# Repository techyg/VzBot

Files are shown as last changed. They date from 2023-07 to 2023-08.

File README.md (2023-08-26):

# Mellow VzBot 330 Kit Information

This is a repository for VZbot mods and info as I went through my build, in July of 2023. I am optimistic the kit will continue to improve. 

Check out my videos here to learn more about this build, including printed part options, first impressions, and a compelte build series. 

https://www.youtube.com/watch?v=h90rvTm2mc8&list=PLpQnpsv1trbRPkbdpc53gmuK3JUCKimgY

Based in the US? Buy your VzBot from Provok3d, who sponsored my build.

https://provok3d.com/product/mellow-vz330-awd/?v=0a10a0b3e53b

# Detailed Info

This content is intended to augment my videos and has more detail that may be helpful for you. This document also includes links to additional components and recommendations for tools that you may need for your build. 

https://github.com/techyg/VzBot/blob/main/Mellow%20VZ%20Bot%20330%20Initial%20impressions.pdf

*** The kit also has several missing fasteners and room for improvement. ** This is not a comprehensive list, but will give you an idea of what additional components you may need to purchase for your kit. I list the missing fastners here as well as some other suggestions for improving the kit.

https://github.com/techyg/VzBot/blob/main/Mellow%20Fly%20Kit%20Suggestions%20VzBot%20330%20Kit.pdf

# Printed Parts

2020 Endscap - Mellow Fly 330 Remix.stl: The stock parts for the 2020 covers are too long and hit the bolt. I created the remix that will work with the Mellow Fly extrusion. You will need to print 8 of these.

VzHextrudort_Motor_Spacer_v1.stl: This helps insulate the motor the heat. I ran into an issue where my motor was causing lower temp filament (PETG) to deform/clog in the extruder due to excessive heat. This is only .5mm thick- print this at a low layer height (.1mm is what I used). I remixed this, original part is from Thingiverse. https://www.thingiverse.com/thing:5777803

If you plan to print PLA or PETG, I definitely recommend using the motor spacer / heat shield. In my testing, I noticed a significant difference in the temp of the extruder vs. the motor, compared to NOT using it. This is because the motor will transfer heat to the extruder much more easily without the motor shield. While it was a little challenging to get exact temps of the motor, using an IR gun I never exceed 60C temps on the extruder and I believe the motor was around 80C. Note that I also did not have the top hat on when printing (but doors were closed), and I also lowered my motor current to .6. 

# Config & Slicer Files

This folder includes all of the printer.cfg and related files that I use. Files are all based on the "stock" VzBot configuration.

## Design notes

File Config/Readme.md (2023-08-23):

Here you find all the files that I am using for my "mostly stock" Mellow VZBot 330 printer, which includes the following:

* Super 8 Pro board
* Goliath Hot End with stock heater cartridge, 24v fan, Generic 3950 Thermistor because my Mellow Fly one broke during install.
* 5160 external stepper motors for X, X1, Y, Y1 run at 48v; single 2209 drivers for E and Z at 24v.
* 750 Watt AC Bed
* Limit switches for X, Y, Z
* CPAP Cooling fan wired to Super 8
* Exhaust fan, RSCS Fans. I am using an external MOSFET to power the RSCS fan due to the higher amp draw. 
* Include file for Provok3d nozzle board. (Optional)

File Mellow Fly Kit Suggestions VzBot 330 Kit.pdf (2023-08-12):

Mellow Fly Kit Sugges0ons VzBot 330 Kit (July 2023 Build)

Installing Corner Brackets: M4 screws are intended here, but heads are too small.
- Include M4 Washers
- Or, provide 12 addi0onal m5x10 BHCS screws with Tnuts

Z Assembly- M3x45’s were needed but not included.
- Provide a quan0ty of 4 M3x45’s SCHS

Heat Inserts will be needed throughout the build (including toolhead, and other loca0ons)
- Include a bag of small M3 heat inserts (3x4mm)

Toolhead requires 2 M3x30 screws that go inside spacers that were not included.
- Include 2 M3x30 screws

AC Inlet is not of sufficient quality.
- Consider providing a "US" version of the AC inlet, with proper IEC wiring colors and a 10A fuse op0on, rather than the included 5A which is probably fine for Europe but not US (since we have half the voltage of EU, so need double the current).

Back Panel
- I ran out of M4x10 screws
- Include an addi0onal 20 M4x10 BHCS

Feet (Assuming Stock feet)
- Include 4 M4x25 SCHS length screws for installing rubber feet
- Include 8 M4x20 SCHS length screws for remaining feet screws

Super 8 Board Moun0ng
- Include M3x8 SHCS (quan0ty at least 10)

Electronics Connectors
- Only spade terminals for Super 8 Pro board are included in kit.
- Include proper sized Spade terminals for 24v and 48v power supply. Recommend at least a 20 pack. (3 for AC input x 2, 6 spaces for +/- x2 on 24v and 48v).
- Include a pack of assorted ferrules for 5160 motor connectors and hot end heater

Wiring
- Include heat shrink that can accommodate 20-24 awg wiring, used for endstops
- Include zip 0es
- Include 6mm and 12mm braided sleeve for keeping back panel wiring 0dy, and for toolhead wire loom / umbilical

CPAP
- Include M2x6 self-tapping screws for CPAP board mount

Exhaust Fan
- Kit was missing 4x M4x50’s. Include those.

RSCS & Side Panels
- Kit was missing m5x12 self-tapping screws. Instead it included M4. I used heat inserts for the fans with M3 screws and washers as a subs0tute. Recommend including the M5x12 self-tapping screws.
- Side panel install required a significant amount of M4x10 screws, and at this point I didn’t have any led. Recommend including at least another 20-30 M4x10’s. At this point I think we’re up to 40 missing M4x10’s.

Front Panels
- 4 Heat inserts needed for latches. Include a small bag of heat inserts.

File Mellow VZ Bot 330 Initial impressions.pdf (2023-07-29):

Mellow VZ Bot 330
Sponsored by Provok3d.com
July 2023

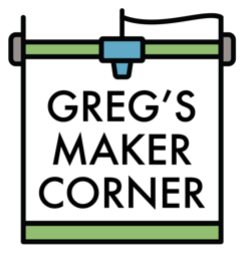
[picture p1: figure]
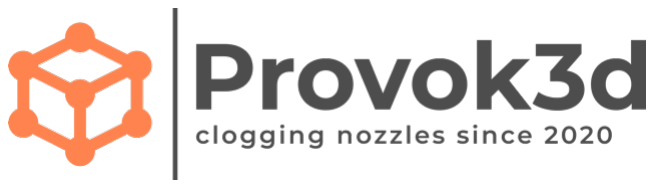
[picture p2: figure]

This document is a writeup of my ini4al impressions immediately following my VzBot 330 Mellow build, which is intended to augment my Ini4al Impressions video posted on Youtube.

Find my Youtube Channel here: h?p://www.gregsmakercorner.com/

If you are considering buying a VzBot 3d printer and are based in the United States, please consider buying from Provok3d who is one of the few authorized dealers in the US. This company sponsored my build and I am VERY appreciaJve!

hJps://provok3d.com/vzbot-330/?v=0a10a0b3e53b

Overall Summary
- Building a VzBot is an ambitious but rewarding build. This machine is intended for DIY enthusiasts and tweakers who want to push 3d printing to the limits. While other DIY designs may offer similar benefits, you might spend a bit more time tweaking, upgrading and going down rabbit holes on to get there.
- With the VzBot, you can expect high speeds (10-20K acceleration, 500 mm/sec as a starting point) with a large build volume (330mm) immediately after completing a well-built, squared and fully tightened printer. With a finely tuned machine, you can expect to achieve 50K-100K accelerations and print beyond 1 meter per second. Wow!
- At the present time, this level of speed and performance is not available "off the shelf" though printers like the Bambu P1P are definitely gaining ground.
- For my very first print, I used a 10K acceleration and 300 mm/sec print speed. The printer had no issue keeping up though it jolts around a bit because the table the printer sat on was not very stable. While I have only done initial testing, I believe this printer easily lives up to the promises of high speed.
- The Mellow Fly VzBot does include the necessary components (CPAP fan, RSCS fans, Goliath hot end) to achieve amazing speeds. However, keep in mind that in order to achieve these speeds you will need a very sturdy and stable surface, and may need to bolt the printer down. You will also need to take many steps to tune and calibrate the printer.
- The Mellow Fly VzBot does not rely on printed parts for any crucial parts of the drive train and gantry, but instead uses CNC metal parts which provides an increased level of rigidity that is suited for high speed and high temp printing. It is possible to build a VzBot with printed parts and still get good results, however.

- With that in mind, you will still need 2 rolls (1kg each) of primary color and 1 roll (1kg) of accent color.
- The VzBot 330 Mellow Kit does not include everything you need to complete the printer build, but it does include most components. See the end of this document for additional part recommendations, tools, etc.
- The Vzbot 330 is an open-source design, with the exception of the CNC metal parts which must be obtained from 3rd party vendors.
- The Github for VzBot 330 design s here: https://github.com/VzBoT3D/VzBoT-Vz330
- According to the Github documentation, a VzBot 330 can be sourced starting at $800. The Mellow Kit is around $1600 but also includes CNC parts and many other high-end components like LDO Super Power motors and rails.

Want to see my build log? Join the VzBot discord and check it out here:

https://discord.com/channels/829828765512106054/1128354020566777938

My recommendations
- I recommend the VzBot Mellow kit for experienced builders who want to be on the cutting edge of 3d printing and squeeze every ounce of performance out of a printer.
- This printer is also ideal for those who want fast print time without having to buy multiple machines and enjoy tinkering and tweaking.
- If you are new to 3d printing I recommend building a Voron 0 first, which would be an excellent printer to “boot strap” many of the parts for this machine which need to be printed in ASA or ABS and will also test your skills/readiness. If you can successfully build a Voron 0 you should be able to complete this build without too many issues.
- This is a DIY printer and building/tweaking is a hobby in itself. If you are mainly interested in the outcome of printing (3d printed parts) and do not enjoy tweaking, fixing, etc. look elsewhere.

VZBot Build Process
- The VzBot documentation has been emerging from simple Github pages with pictures, to what I would consider an "MVP" (minimum viable product) philosophy. Think of the manual more as guidelines vs. step by step instructions.
- I went into this build with the idea that I would build it as stock as possible. There were a few places I was tempted to go outside of stock but for the most part I resisted the urge and stuck with the intended design. I felt this would be best to give a good review of the kit and help guide other builders.

Mellow Fly Kit
- The Mellow kit is a good start and has high quality components where it really matters, especially for the motors and of course CNC parts. You will definitely need to augment your kit with additional components to complete it. There are some obvious components that you will need- for example a Raspberry Pi or equivalent. I also needed several different sizes of fasteners that weren't included. I've listed the vast majority of components I used in the video description if you would like to get a feel. Expect to spend around $xx-$xxx depending on what you may already have on hand.

Build Time

- It took me less than 3 weeks to build this printer. I was working on it part-time, weekends and evenings, and also recording video along the way. An experienced builder who has previously built Core XY printers (such as Voron, RatRig, or Annex) could possibly complete the build in a long weekend "best case". Realistically, I would budget at least 1-2 weeks to build.

Mechanical Build
- The mechanical build was very straight forward up until back panel. The build complexity is very similar to build a Voron Trident, or a Prusa Mk3/4.
- Unfortunately, the panels needed additional prep work. Drilling was required to open up holes for power supply (which were too tight), and new holes were required for DIN Rail mounting.
- Drilling aluminum is not particularly difficult with the proper tools, but it may be a barrier for some.

Electronics, Wiring and Crimping:

- The electronics portion of the build is tedious and time consuming, and could be a significant challenge especially for those who do not have experience crimping, soldering, etc.
- WARNING. The Mellow Fly kit I received included an under spec’d AC power inlet, and it should be discarded. Some builders have reported the inlet melting when heating both the bed and hot end, which draws a significant amount of power. I purchased a replacement AC inlet on Amazon but it would be best to get one (a standard c14 ac inlet) from a reputable company like Mouser or Digikey ideally with a certification.
- You will be working with mains power, two power supplies (24v and 48v), and an SSR for the AC bed. While this isn't difficult to wire up, you really need to use care while wiring and also make sure you are earthing properly. Consult with an electrician if you are not sure.
- You will need to carefully consider layout of the wiring. The VzBot design team deliberately does not prescribe a wiring layout, because there are so many possible directions to take, as well as optional/potential upgrades. For example, some builders may opt for multiple SSR's for high temp chamber heating, as well as additional fans.
- My kit did not include very many connectors outside of JST and a few small spade terminals for the Super 8 Pro board. With that in mind you will need to source these depending on the direction you go. You will also need several different crimpers. I ended up crimping Spade Terminals for power supplies, Raspberry Pi, JST PH for fan connectors to the 5160's, Ferrules for the 5160's, and JST XH connectors for many other connections (fans, thermistors, etc.).

Where I ran into challenges

- On occasion the manual was not as clear as I was hoping, and I had to consult the CAD diagram for clarification. In some cases, I couldn't find what I was looking for, so I went and asked in the Discord. There are several helpful members there and also times where the design team answered my question. I found the community very helpful though I know Discord is not everyone's cup of tea.
- Having to drill the back panel was not expected but it wasn't too difficult. Fortunately, I had the proper drill bits and tools.
- It took me a while to figure out how I wanted to lay out electronics including the DIN mount, wire channels, wagos, etc. I wanted to go with a stock layout as much as possible. I also looked at a few other builds in the Discord showcase and build log to decide what I wanted to do.

- I was stuck for a few hours troubleshooting klipper communication errors with the 5160 motor drivers. Thanks to discord users, including porkcube who helped me sort out a setting I needed for the driver to work. I also noticed the stepper adapters use a connector that does not really seat well, and reseating/firmly connecting these also helped.
- Another frustrating issue was the mellow fly thermistor broke while I was installing it. I later learned that this is common due to the type of cement they use to secure the wiring. I was able to order a replacement thermistor, though not a PT1000, but has been working fine. I recommend getting a few of the Triangle Labs thermistors from AliExpress.
- The machine is very heavy. The further I went in the build, the heavier the machine got. I recommend holding off on installing the heated bed / plate until the end of the build for this reason.
- As I went through my build log I created recommendations for the manual as well as the Mellow Fly kit. You can search my build log for “RECOMMENDATIONS” to see these, and I also plan to provide a consolidated list to both VzBot design team, and Mellow.

Additional components I used or recommend are below. These are all affiliate links. If you use these links, it helps me out and costs you nothing.

Polylite ASA (2 rolls of primary color, 1 roll of accent color) - https://amzn.to/44MV8Dz
SSR DIN Mount - https://amzn.to/3rVonFB
HEPA filter - https://amzn.to/3rL2PLX
LED Light - https://amzn.to/45809Gw
Rubber Feet - https://amzn.to/44NqUjM
Tobsun 24v to 5v DC-DC converter - https://amzn.to/43NzcXL
AC Inlet - https://amzn.to/457NROi
100K M3 Thermistor - https://amzn.to/44N3yL5
Small .25 inch Braided Cable Sleeve for Back Panel Motor Wiring - https://amzn.to/457et2g Medium .5 inch Braided Cable Sleeve for Toolhead Wiring - https://amzn.to/3OcDcez
M2 Flathead Self Tapping Screws - https://amzn.to/44R9dzV
M2.5 Button Head Screws - https://amzn.to/4512XG5
Reusable Cable Ties - https://amzn.to/3QhfekU
Synthetic Lube for Lead Screw: https://amzn.to/3FUyptf Blue Permatex for Fasteners: https://amzn.to/3ATPmjE Isopropyl Alcohol (Spray Bottle): https://amzn.to/3lRp1Pe 16 awg wiring for AC - https://amzn.to/3YkcfdG
Heat shrink kit - https://amzn.to/3Qc4STw
Spade Terminals - https://amzn.to/3YkZhw7

Tools I used or recommend are below. These are all affiliate links. If you use these links, it helps me out and costs you nothing.

PA-09 Engineer Crimping tool: https://amzn.to/3aLgZB9
Titan Ratcheting Crimper: https://amzn.to/3aKaONE
Ferrule Crimping Tool: https://amzn.to/2Z3axDb
Heat gun: https://amzn.to/3OyD2P1
Drill / Tap combo: https://amzn.to/3QlLSBZ
Drill bits: https://amzn.to/3Ydc43z

Drill Bit Cutting Fluid: https://amzn.to/3DwB7oW Hakko Soldering Station: https://amzn.to/3FZtsiM Hakko Heat Insert Tool: https://amzn.to/3aLh6N5
Small Screwdriver Set: https://amzn.to/3DNNc7h
Heavy Duty Scissors: https://amzn.to/3DObKNm
Metric Bondhus Hex Drivers (Ball Driver): https://amzn.to/3vpjti8 Metric Wiha Hex Drivers: https://amzn.to/3vp5Tv4
Metal Ruler: https://amzn.to/3n5YsoQ

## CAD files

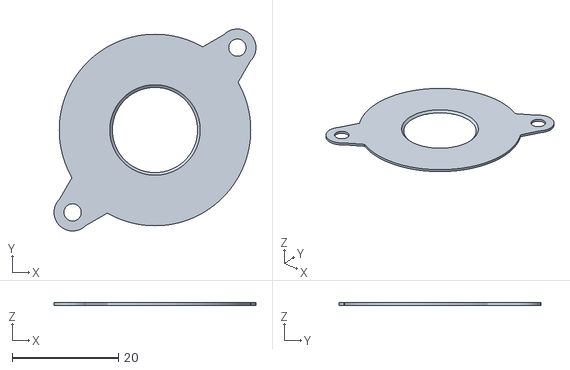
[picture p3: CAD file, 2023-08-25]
VzHextrudort_Motor_Spacer_v1.stl
38.0 x 38.0 x 0.5

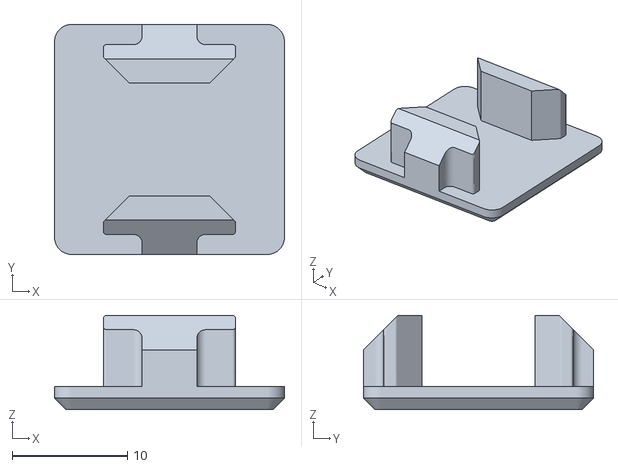
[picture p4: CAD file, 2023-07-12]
2020 Endcap - Mellow Fly 330 Remix.stl
20.0 x 20.0 x 8.20

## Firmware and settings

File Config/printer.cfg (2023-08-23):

[include mainsail.cfg]
[virtual_sdcard]
path: /home/pi/printer_data/gcodes
on_error_gcode: CANCEL_PRINT

### For Fly Super 8 V1.3 ####
### And Mellow Kit  ####
### For Fly Super pro 8, the SPI bus is spi1A
### For Fly Super 8 V1.3, the SPI bus is spi3

[include mainsail.cfg]
[display_status]
[exclude_object]
[include printmacros.cfg]
#[include inputshaper.cfg]

[pause_resume]
recover_velocity: 350

##### VzBoT############
#######################

[printer]
kinematics: corexy
max_velocity: 2500
max_accel: 15000
#max_accel_to_decel: 5000
max_z_velocity: 20
max_z_accel: 1500
square_corner_velocity: 10

########################
########################

[mcu]
serial: /dev/serial/by-id/usb-Klipper_stm32h723xx_380037000751313430323835-if00  # put your own Serial here.
restart_method: command

[temperature_sensor FLY-Super8]
sensor_type: temperature_mcu

[mcu rpi]
serial: /tmp/klipper_host_mcu

[temperature_sensor raspberry_pi]
sensor_type: temperature_host
min_temp: 10
max_temp: 100

########################
########################

## My Motors are laid out as such, so I updated my config per below.
#
#  Back of Printer
#   X1        Y1
#
#   Y         X 
#  Front of Printer

#  How I installed motors on my board. Use this as a reference for your setup (update as necessary for your driver positions)
#
# After installing, run stepper_buzz to confirm motors are working before doing any homing.
#
# Pinout Ref: https://mellow.klipper.cn/#/board/fly_super8/pins
#  Top of board      Driver # from Pinout     Pins from Pinout (Step, Dir, Enable, CS/UART)
#   E (2209)         Driver_7                 PE6, PG6, PG7, PG5 
#   Y1 (5160)        Driver_6                 PE0, PG3, PG4, PG2
#   Y (5160)         Driver_5                 PE1, PF0, PC15, PF1
#   X1 (5160)        Driver_4                 PE15, PE11, PF2, PE10
#   X (5160)         Driver_3                 PE14, PE8, PE9, PE7
#   SKIPPED          Driver_2                 PE4, PG0, PG1, PF15
#   SKIPPED          Driver_1                 PE3, PF13, PF14, PF12
#   Z (2209)         Driver_0                 PE2, PC5, PF11, PC4
# Bottom of Board (near power inputs)

[stepper_x]
##	in Driver_3 Position
step_pin: PE14
dir_pin: !PE8
enable_pin: !PE9
rotation_distance: 40
microsteps: 16
full_steps_per_rotation: 200  
endstop_pin: PG11            #make sure to set the correct pin here.
position_endstop: 0
position_min: 0
position_max: 300
homing_speed: 50 
homing_retract_dist: 0

[tmc5160 stepper_x] 
#spi_bus: spi1
spi_software_sclk_pin: PB3
spi_software_miso_pin: PB4
spi_software_mosi_pin: PB5
cs_pin: PE7
interpolate: false
run_current: 1.8 # was 2
sense_resistor: 0.033
stealthchop_threshold: 0
driver_TBL: 0
driver_TOFF: 1
driver_DISS2G: 1
driver_DISS2VS: 1
driver_TPFD: 0

[stepper_x1]
##	in Driver_4 Position
step_pin: PE15
dir_pin: !PE11
enable_pin: !PF2
rotation_distance: 40
microsteps: 16
full_steps_per_rotation: 200
#endstop_pin: tmc5160_stepper_x:virtual_endstop 

[tmc5160 stepper_x1]
#spi_bus: spi1
spi_software_sclk_pin: PB3
spi_software_miso_pin: PB4
spi_software_mosi_pin: PB5
cs_pin: PE10
interpolate: false
run_current: 1.8
sense_resistor: 0.033
stealthchop_threshold: 0
driver_TBL: 0
driver_TOFF: 1 
driver_DISS2G: 1
driver_DISS2VS: 1
driver_TPFD: 0

[stepper_y]
##	in Driver_5 position
step_pin: PE1
dir_pin: !PF0
enable_pin: !PC15
rotation_distance: 40
microsteps: 16
full_steps_per_rotation: 200  
endstop_pin: PG12                 #make sure to set the correct pin here.
position_endstop: -0
position_min: 0
position_max: 300
homing_speed: 50  
homing_retract_dist: 0

[tmc5160 stepper_y] 
#spi_bus: spi1
spi_software_sclk_pin: PB3
spi_software_miso_pin: PB4
spi_software_mosi_pin: PB5
cs_pin: PF1
interpolate: false
run_current: 1.8
sense_resistor: 0.033
stealthchop_threshold: 0
driver_TBL: 0
driver_TOFF: 1
driver_DISS2G: 1
driver_DISS2VS: 1
driver_TPFD: 0

[stepper_y1]
##	in Driver_6 position
step_pin: PE0
dir_pin: !PG3
enable_pin: !PG4
rotation_distance: 40
microsteps: 16
full_steps_per_rotation: 200
#endstop_pin: tmc5160_stepper_y:virtual_endstop  

[tmc5160 stepper_y1] 
#spi_bus: spi1
spi_software_sclk_pin: PB3
spi_software_miso_pin: PB4
spi_software_mosi_pin: PB5
cs_pin: PG2
interpolate: false
run_current: 1.8
sense_resistor: 0.033
stealthchop_threshold: 0
driver_TBL: 0
driver_TOFF: 1
driver_DISS2G: 1
driver_DISS2VS: 1
driver_TPFD: 0

#########################

[stepper_z]
## In Driver_0 position
step_pin: PE2
dir_pin: PC5
enable_pin: !PF11
microsteps: 32
rotation_distance: 4
endstop_pin: PG10              #make sure to set the correct pin here.
#position_endstop: 0.0
position_max: 400
full_steps_per_rotation: 200
homing_retract_dist: 5.0
homing_positive_dir: false
homing_speed: 5.0
second_homing_speed: 2.5

[tmc2209 stepper_z]
interpolate: false
uart_pin: PC4
run_current: 1.2
stealthchop_threshold: 0

[extruder]
## In Driver_7 position
### Vz-HextrudORT
step_pin: PE6
dir_pin: !PG6
enable_pin: !PG7
microsteps: 16
#VZHextrudort LDO 20mm
rotation_distance: 3.40
nozzle_diameter: 0.4
filament_diameter: 1.750

heater_pin: PB0
#sensor_type: PT1000
sensor_type: Generic 3950
sensor_pin: PF4

#control: pid
#pid_Kp=28.737 
#pid_Ki=1.935 
#pid_Kd=106.684
min_temp: 0
max_temp: 270
full_steps_per_rotation: 200
max_extrude_only_distance: 1000.0
max_extrude_cross_section: 500
max_extrude_only_velocity: 200
max_extrude_only_accel: 10000
min_extrude_temp: 0
pressure_advance: 0.02
pressure_advance_smooth_time: 0.03

[tmc2209 extruder]
uart_pin: PG5
interpolate: false
run_current: 0.7
sense_resistor: 0.110

########################
########################

[heater_bed]
heater_pin: PE5
sensor_type: Generic 3950
sensor_pin: PC1
max_power: .85
#control: pid
#pid_Kp: 66.746
#pid_Ki: 3.504
#pid_Kd: 317.878
min_temp: 0
max_temp: 130


########################
#### FANS ##############
########################

#CPAP 
[fan] 
##	Print Cooling Fan - GPIO26
pin: PF8
max_power: 1
#cycle_time: 0.002
#hardware_pwm: false
#shutdown_speed: 0

[heater_fan hotend_fan]
##	Hotend Fan - FAN0 Connector
## in case of watercooler that is 24V use a Heater Pin like PF7 Heat3 for a larger mosfet that can handle more amps.
pin: PA0
max_power: 1.0
kick_start_time: 0.5
heater: extruder
heater_temp: 50.0

[controller_fan pi_fan]
##	Pi Fan - FAN2 Connector
##  Turn the fan on when the hot end powers up. 
pin: PA2
max_power: 1.0
kick_start_time: 0.5
heater: extruder

[fan_generic exhaust_fan]
#  Exhaust fan - FAN4
pin: PA15
max_power: 1.0
shutdown_speed: 0.0
kick_start_time: 5.0
#fan_speed: 1.0

[fan_generic rscs_fan]
#  Exhaust fan - FAN5
pin: PB10
max_power: 1.0
shutdown_speed: 0.0
kick_start_time: 3.0
off_below: 0.10
#fan_speed: 1.0

#[fan_generic Exhaust_fan]
##  exhaust fan - In FAN4
#pin: PA15
#max_power: 1
#shutdown_speed: 0
#kick_start_time: 0.1
#off_below: 0.10

#[fan_generic chamber_fan]
###  chamber fan - In FAN9 Positon
#pin: PD15
#max_power: 1
#shutdown_speed: 0
#kick_start_time: 0.1
#off_below: 0.10

#[fan_generic RSCS]
##  RSCS Fans - In FAN1 Positon
#pin: PA1
#max_power: 1
#shutdown_speed: 0
#kick_start_time: 0.1
#off_below: 0.10

#[controller_fan driver_fan] 
# This is if you connect your driver fan to Super8 
#or if you want to add fan to the Super8. Other wise connect them in the driver fan ports
#stepper: stepper_x
#pin: PD14
#max_power: 1
#shutdown_speed: 0
#kick_start_time: 0.1
#off_below: 0.10

########################
########################

#[temperature_sensor chamber]  optional for chamber temp
#sensor_type: NTC 100K MGB18-104F39050L32
#pullup_resistor: 4700
#sensor_pin: PF5
#min_temp: 0
#max_temp: 60
#gcode_id: C: C

#[temperature_sensor Bed_Edge]
#Sensor_type: Generic 3950
#sensor_pin:PF4

###########################################
#########Custom PINs Definition ############
###########################################

#[output_pin LED]
#In FAN8 position if 12 or 5V
#When 24V use a heater pin like Heat4 PF6
#pin: PF6
#pwm: false
#value: 1
#shutdown_value:1
### gcode command: SET_PIN PIN=LED value=0 to 1

#*# <---------------------- SAVE_CONFIG ---------------------->
#*# DO NOT EDIT THIS BLOCK OR BELOW. The contents are auto-generated.
#*#
#*# [extruder]
#*# control = pid
#*# pid_kp = 21.412
#*# pid_ki = 1.878
#*# pid_kd = 61.023
#*#
#*# [heater_bed]
#*# control = pid
#*# pid_kp = 52.547
#*# pid_ki = 1.557
#*# pid_kd = 443.367
#*#
#*# [input_shaper]
#*# shaper_type_x = mzv
#*# shaper_freq_x = 107.4
#*# shaper_type_y = mzv
#*# shaper_freq_y = 76.0
#*#
#*# [stepper_z]
#*# position_endstop = 0.075

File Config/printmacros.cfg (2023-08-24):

################################################################################################
################################################################################################
#####				MACROS					

##################

########################	

[gcode_macro Disable_Steppers]
gcode:
    M84
#### 
# To make your print_start macro work you need to put a bit of code in your slicer too. Put this in the: Start G-code in SS at printer settings and then Custom G-code. Put in the code down below there.
#
#    PRINT_START EXTRUDER_TEMP={first_layer_temperature[initial_extruder] + extruder_temperature_offset[initial_extruder]} BED_TEMP=[first_layer_bed_temperature]
####
#    In your End G-code you simply put:
#    print_end    ;end script from macro
####

[gcode_macro PRINT_START]
gcode:
    {% set BED_TEMP = params.BED_TEMP|default(100)|float %}
    {% set EXTRUDER_TEMP = params.EXTRUDER_TEMP|default(190)|float %}
    # Start bed heating
    M140 S{BED_TEMP}
    # Wait for bed to reach temperature
    M190 S{BED_TEMP}
    M117 Homing...                 ; display message
    G28
    G1 Z20.0 F600 ;move the platform down 15mm
    G1 X20 Y20 F3000
    # Set and wait for nozzle to reach temperature
    M109 S{EXTRUDER_TEMP}
    G1 X1.8 Y10 F3000
    G1 Z0.24 F240
    G92 E0 ;zero the extruded length again
    G1 Y190 E15.0 F1500.0 ; intro line
    G1 X2.3 F5000
    G1 Y10 E30 F1200.0 ; intro line
    G92 E0.0 ;zero the extruded length again
    G1 F9000
    M117 Printing...

[gcode_macro PRINT_END]
#   Use PRINT_END for the slicer ending script
gcode:
    #   Get Boundaries
    {% set max_x = printer.configfile.config["stepper_x"]["position_max"]|float %}
    {% set max_y = printer.configfile.config["stepper_y"]["position_max"]|float %}
    {% set max_z = printer.configfile.config["stepper_z"]["position_max"]|float %}
    
    #   Check end position to determine safe directions to move
    {% if printer.toolhead.position.x < (max_x - 15) %}
        {% set x_safe = 10.0 %}
    {% else %}
        {% set x_safe = -10.0 %}
    {% endif %}

    {% if printer.toolhead.position.y < (max_y - 15) %}
        {% set y_safe = 10.0 %}
    {% else %}
        {% set y_safe = -10.0 %}
    {% endif %}

    {% if printer.toolhead.position.z < (max_z - 2) %}
        {% set z_safe = 50.0 %}
    {% else %}
        {% set z_safe = max_z - printer.toolhead.position.z %}
    {% endif %}
    
    #  Commence PRINT_END
    M400                             ; wait for buffer to clear
    G92 E0                           ; zero the extruder
    G1 E-4.0 F3600                   ; retract
    G91                              ; relative positioning
    G0 Z{z_safe} + Z10 F3600         ; move nozzle up
    G0 X{x_safe} Y{y_safe} F20000    ; move nozzle to remove stringing
    M104 S0                          ; turn off hotend
    M140 S0                          ; turn off bed
    M106 S0                          ; turn off fan
    G90                              ; absolute positioning
    G0 X{max_x / 2} Y{max_y - 5} F3600   ; park nozzle at rear
    M84
    BED_MESH_CLEAR
    SET_HEATER_TEMPERATURE HEATER=chamber TARGET=0
    M117 Finished!

### Speed test macro.
# Home, get position, throw around toolhead, home again.
# If MCU stepper positions (first line in GET_POSITION) are greater than a full step different (your number of microsteps), then skipping occured.
# We only measure to a full step to accomodate for endstop variance.
# Example: TEST_SPEED SPEED=300 ACCEL=5000 ITERATIONS=10

[gcode_macro TEST_SPEED]
gcode:
	# Speed
	{% set speed  = params.SPEED|default(printer.configfile.settings.printer.max_velocity)|int %}
	# Iterations
	{% set iterations = params.ITERATIONS|default(5)|int %}
	# Acceleration
	{% set accel  = params.ACCEL|default(printer.configfile.settings.printer.max_accel)|int %}
	# Bounding inset for large pattern (helps prevent slamming the toolhead into the sides after small skips, and helps to account for machines with imperfectly set dimensions)
	{% set bound = params.BOUND|default(20)|int %}
	# Size for small pattern box
	{% set smallpatternsize = SMALLPATTERNSIZE|default(20)|int %}
	
	# Large pattern
		# Max positions, inset by BOUND
		{% set x_min = printer.toolhead.axis_minimum.x + bound %}
		{% set x_max = printer.toolhead.axis_maximum.x - bound %}
		{% set y_min = printer.toolhead.axis_minimum.y + bound %}
		{% set y_max = printer.toolhead.axis_maximum.y - bound %}
	
	# Small pattern at center
		# Find X/Y center point
		{% set x_center = (printer.toolhead.axis_minimum.x|float + printer.toolhead.axis_maximum.x|float ) / 2 %}
		{% set y_center = (printer.toolhead.axis_minimum.y|float + printer.toolhead.axis_maximum.y|float ) / 2 %}
		
		# Set small pattern box around center point
		{% set x_center_min = x_center - (smallpatternsize/2) %}
		{% set x_center_max = x_center + (smallpatternsize/2) %}
		{% set y_center_min = y_center - (smallpatternsize/2) %}
		{% set y_center_max = y_center + (smallpatternsize/2) %}

	# Save current gcode state (absolute/relative, etc)
	SAVE_GCODE_STATE NAME=TEST_SPEED
	
	# Output parameters to g-code terminal
	{ action_respond_info("TEST_SPEED: starting %d iterations at speed %d, accel %d" % (iterations, speed, accel)) }
	
	# Set new limits
	SET_VELOCITY_LIMIT VELOCITY={speed} ACCEL={accel} ACCEL_TO_DECEL={accel / 2}

    #Home
    #G28

	# Go to starting position
	G0 X{x_min+10} Y{y_min+10} Z{bound + 20} F{speed*60}

	{% for i in range(iterations) %}
		# Large pattern
			# Diagonals
			G0 X{x_min+10} Y{y_min+10} F{speed*60}
			G0 X{x_max-30} Y{y_max-30} F{speed*60}
			G0 X{x_min+10} Y{y_min+10} F{speed*60}
			G0 X{x_max-30} Y{y_max-30} F{speed*60}
			G0 X{x_min+10} Y{y_min+10} F{speed*60}
			G0 X{x_max-30} Y{y_max-30} F{speed*60}
			
			# Box
			G0 X{x_min+10} Y{y_min+10} F{speed*60}
			G0 X{x_min+10} Y{y_max-30} F{speed*60}
			G0 X{x_max-30} Y{y_max-30} F{speed*60}
			G0 X{x_max-30} Y{y_min+10} F{speed*60}
		
		# Small pattern
			# Small diagonals 
			G0 X{x_center_min} Y{y_center_min} F{speed*60}
			G0 X{x_center_max} Y{y_center_max} F{speed*60}
			G0 X{x_center_min} Y{y_center_min} F{speed*60}
			G0 X{x_center_max} Y{y_center_min} F{speed*60}
			G0 X{x_center_min} Y{y_center_max} F{speed*60}
			G0 X{x_center_max} Y{y_center_min} F{speed*60}
			
			# Small box
			G0 X{x_center_min} Y{y_center_min} F{speed*60}
			G0 X{x_center_min} Y{y_center_max} F{speed*60}
			G0 X{x_center_max} Y{y_center_max} F{speed*60}
			G0 X{x_center_max} Y{y_center_min} F{speed*60}
	{% endfor %}

	# Restore max speed/accel/accel_to_decel to their configured values
	SET_VELOCITY_LIMIT VELOCITY={printer.configfile.settings.printer.max_velocity} ACCEL={printer.configfile.settings.printer.max_accel} ACCEL_TO_DECEL={printer.configfile.settings.printer.max_accel_to_decel} 
	# Restore previous gcode state (absolute/relative, etc)
	RESTORE_GCODE_STATE NAME=TEST_SPEED
    G0 X115 Y115 Z30

[gcode_macro exhaustfan_on]
gcode: 
	SET_FAN_SPEED FAN=Exhaust_fan SPEED=1
###	
	
[gcode_macro exhaustfan_off]
gcode: 
	SET_FAN_SPEED FAN=Exhaust_fan SPEED=0
	
	
###		
	
[gcode_macro enclosurefan_on]
gcode: 
	SET_FAN_SPEED FAN=chamber_fan SPEED=1

###			
	
[gcode_macro enclosurefan_off]
gcode: 
	SET_FAN_SPEED FAN=chamber_fan SPEED=0


[gcode_macro RSCS_on]
gcode: 
	SET_FAN_SPEED FAN=RSCS SPEED=1
###	
	

[gcode_macro RSCS_off]
gcode: 
	SET_FAN_SPEED FAN=RSCS SPEED=0
		
###

[gcode_macro LED_on]
gcode:
	SET_PIN PIN=LED value=1   


[gcode_macro LED_off]
gcode:
	SET_PIN PIN=LED value=0  

###	
	
[gcode_macro PA_tunning]
gcode: 
	SET_VELOCITY_LIMIT SQUARE_CORNER_VELOCITY=1 ACCEL=500
	TUNING_TOWER COMMAND=SET_PRESSURE_ADVANCE PARAMETER=ADVANCE START=0 FACTOR=.005


[gcode_macro TEST_RESONNANCES_X]
gcode:
 TEST_RESONANCES AXIS=X


[gcode_macro TEST_RESONNANCES_Y]
gcode:
 TEST_RESONANCES AXIS=Y

[gcode_macro Automatic_Inputshaper]
gcode:
  SHAPER_CALIBRATE
  Save_config


[gcode_macro enable_stepper]
gcode:
 SET_STEPPER_ENABLE STEPPER=stepper_x ENABLE=1
 SET_STEPPER_ENABLE STEPPER=stepper_x1 ENABLE=1
 SET_STEPPER_ENABLE STEPPER=stepper_y ENABLE=1
 SET_STEPPER_ENABLE STEPPER=stepper_y1 ENABLE=1


[gcode_macro PID_Calibrate_dropdown]
gcode:
    {% set heater = params.HEATER|string %}
    {% set target = params.TARGET|int %}
    PID_CALIBRATE HEATER={heater} TARGET={target}
################################################################################################
################################################################################################

[idle_timeout]
timeout: 1800
gcode =
  {% if printer.pause_resume.is_paused %}
    M104 S0
  {% else %}
    TURN_OFF_HEATERS
    #M84
  {% endif %}


################################################################################################
##                                        Probe                                               ##
################################################################################################
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
